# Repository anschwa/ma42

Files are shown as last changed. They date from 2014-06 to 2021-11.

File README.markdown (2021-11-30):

The MA42 Keyboard
=================

A programmable 42% mechanical keyboard for Dvorak.

Created by Michael Gobeli and Adam Schwartz.

With the help of:

- [jdcarpe](https://geekhack.org/index.php?action=profile;u=17386)
- [thechemist](https://geekhack.org/index.php?action=profile;u=27275)
- [geekhack.org](https://geekhack.org/index.php)

# Editor

[TMK Keymap Editor for MA42](http://anschwa.com/tmk_keyboard/editor/ma42/index.html).

Based on the [TMK Keymap Editor for the HHKB](http://www.tmk-kbd.com/tmk_keyboard/editor/hhkb/index.html).

# Photos

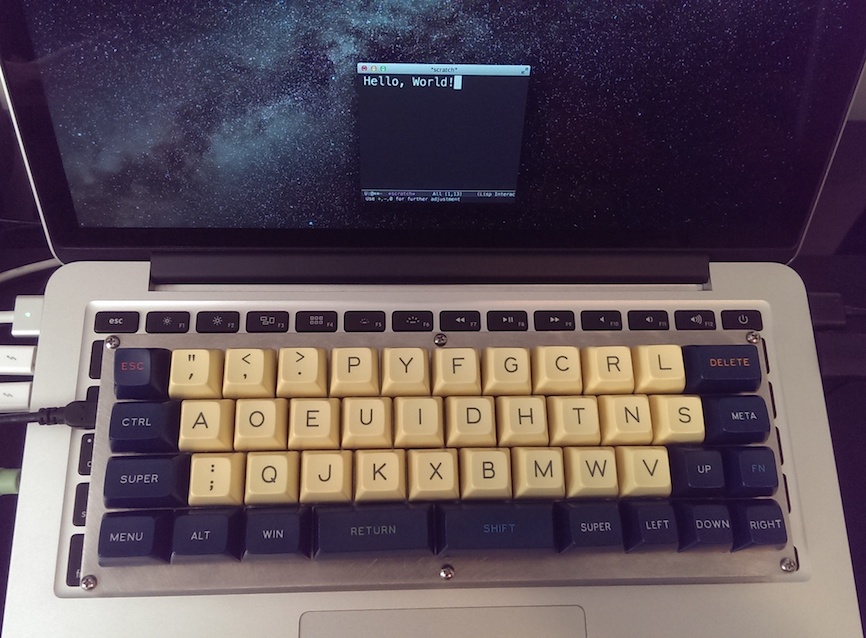
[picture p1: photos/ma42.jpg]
MA42 on top of rMBP


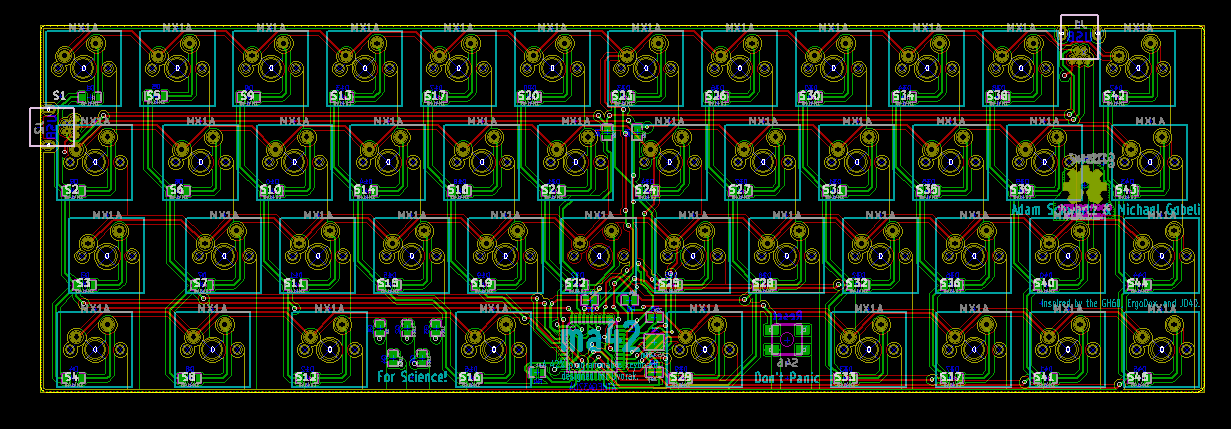
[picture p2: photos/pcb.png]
MA42 PCB revB


# License
The MA42 project is licensed under MIT unless otherwise noted.

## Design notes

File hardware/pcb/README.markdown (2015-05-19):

The MA42 PCB
============

The MA42 PCBs are licensed under [CC BY-SA 3.0](https://creativecommons.org/licenses/by-sa/3.0/us/).

However, this is due to a misunderstanding with the `GH60` licensing.

The `GH60` KiCad Source we accesed in July 2014 was distributed as "open source" without any explicit licence.

- [gh60 downloads 2014](https://web.archive.org/web/20140701221151/http://blog.komar.be/projects/gh60-programmable-keyboard/)

Currently, the `GH60` download page was updated with a `CC BY-SA 3.0` license sometime after October 17 2014 Many months after our projects completion.

- [gh60 downloads 2015+](http://blog.komar.be/projects/gh60-programmable-keyboard/)

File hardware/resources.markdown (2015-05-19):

## Articles
- [How to Design the Perfect PCB – Part 1](http://www.michaelhleonard.com/how-to-design-the-perfect-pcb-part1)
- [How to Design the Perfect PCB – Part 2](http://www.michaelhleonard.com/how-to-design-the-perfect-pcb-part2/)

## Videos
- [Solder ATmega32u4](http://vimeo.com/51312926)
- [Solder Crystal Oscillator](http://vimeo.com/51713766)

## GH60
- [How to make a keyboard - The Matrix](http://blog.komar.be/how-to-make-a-keyboard-the-matrix/)
- [GH60 GitHub](https://github.com/komar007/ghkb)

## ErgoDox
- [Ergodox GitHub](https://github.com/bishboria/ErgoDox)

## PCB Manufacturer
- [Advanced Circuits](http://www.4pcb.com/)
- [OSH Park](http://oshpark.com/)
- [ExpressPCB](http://www.expresspcb.com/)

## PCB Desgin Software
- [KiCad](http://www.kicad-pcb.org/display/KICAD/KiCad+EDA+Software+Suite)
- ~~[ExpressPCB](http://www.expresspcb.com/ExpressPCBHtm/Free_cad_software.htm)~~

## Schematics
- [Teensy](https://www.pjrc.com/teensy/schematic.html)

## Layout
- [Keyboard Layout Editor](http://www.keyboard-layout-editor.com/)

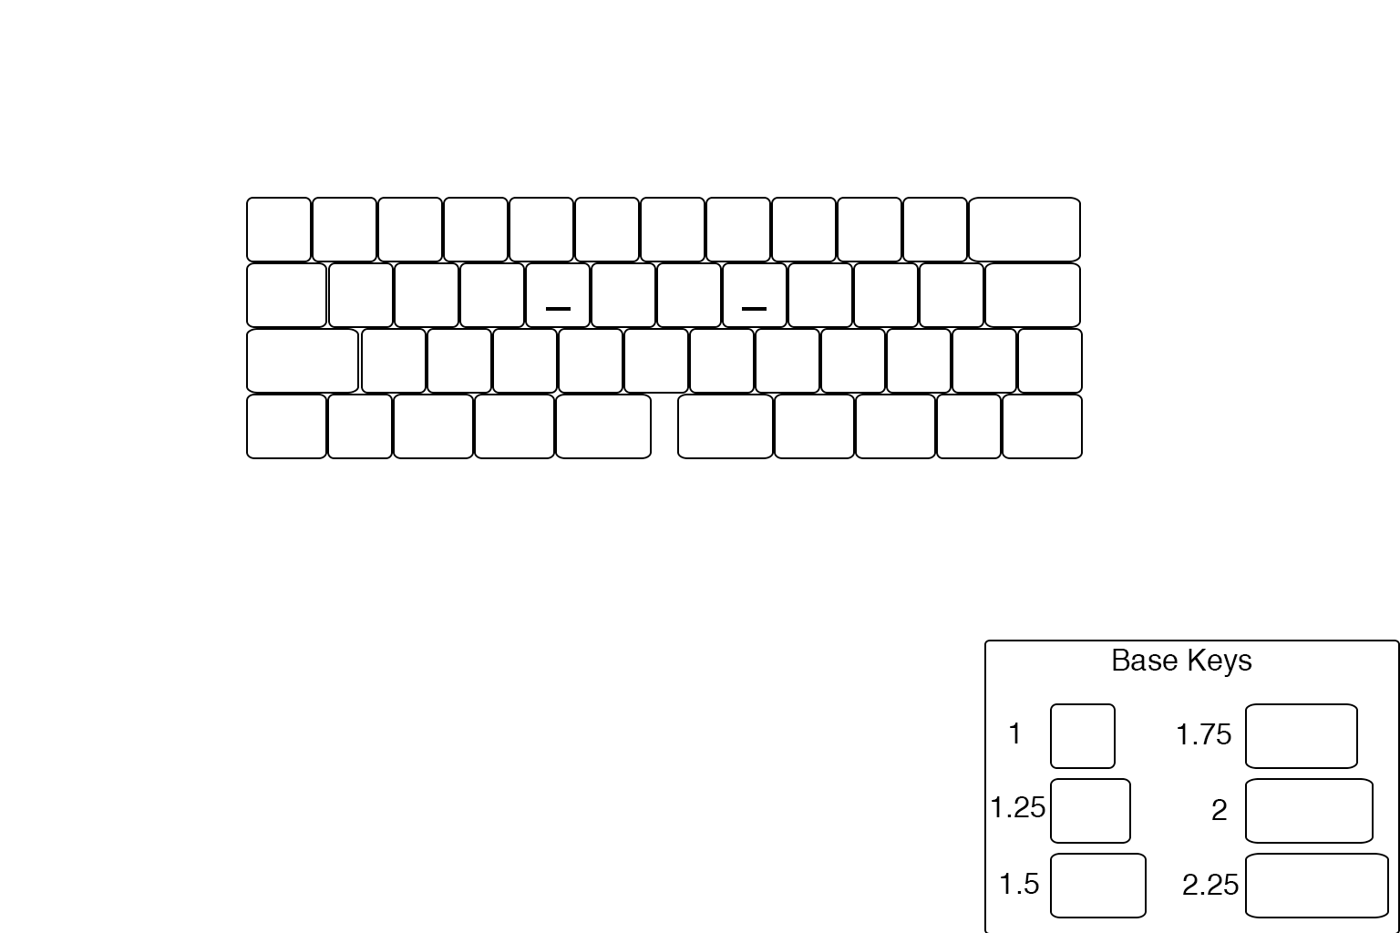
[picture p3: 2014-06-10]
hardware/layout/layout_b.png

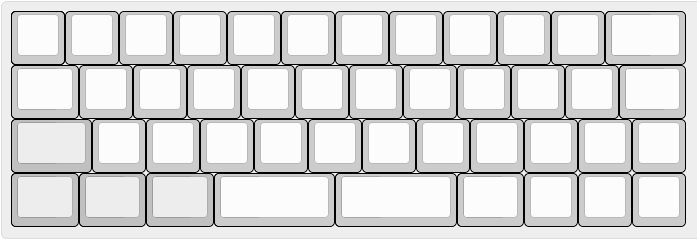
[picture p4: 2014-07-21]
hardware/layout/layout_d.png

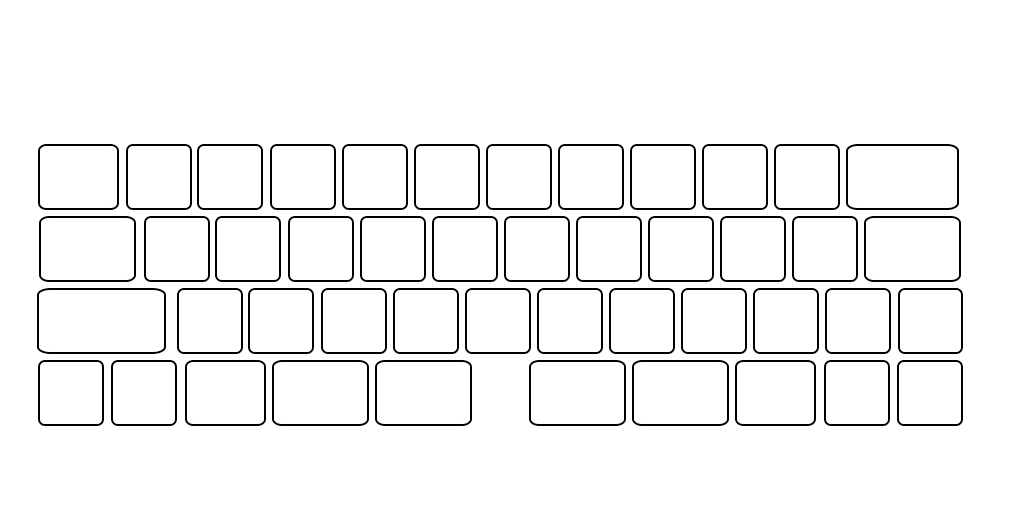
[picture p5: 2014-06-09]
hardware/layout/layout_a.png

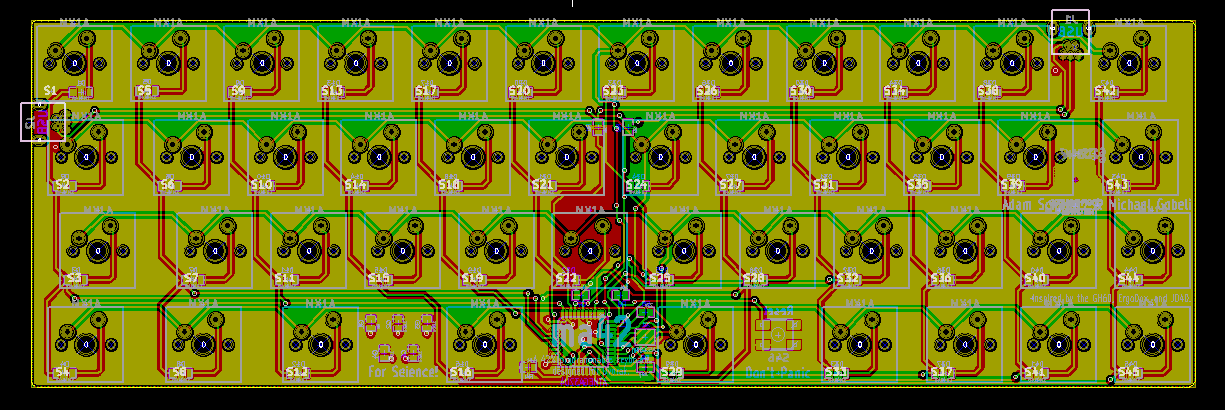
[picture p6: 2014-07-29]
hardware/pcb/revB/ma42_PCB_revB/resources/pcb1.PNG

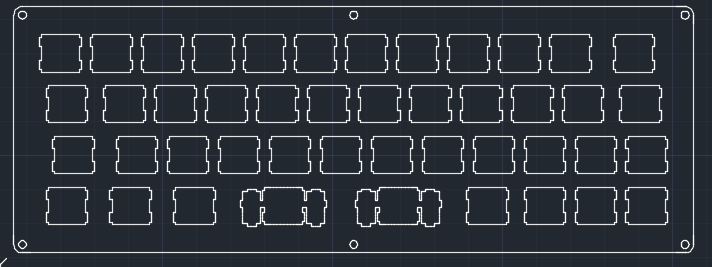
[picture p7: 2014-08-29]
hardware/case/revB/plate/Capture.PNG

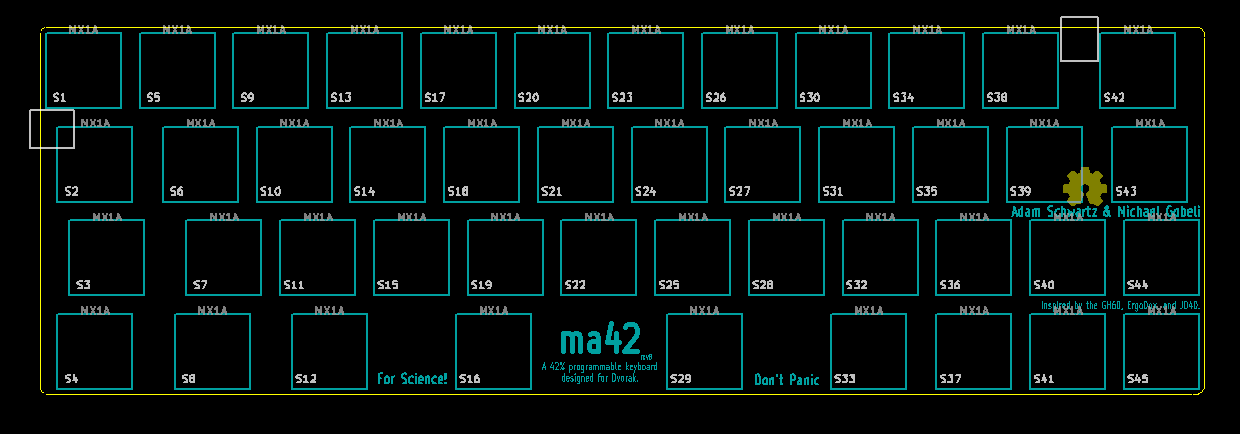
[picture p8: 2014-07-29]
hardware/pcb/revB/ma42_PCB_revB/resources/pcb3.PNG

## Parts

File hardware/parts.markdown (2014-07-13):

# Components Parts List

## Microcontroller
- [Leonardo Pro Micro](http://www.ebay.com/itm/Leonardo-Pro-Micro-ATmega32U4-Arduino-IDE-1-0-3-Bootloader-replace-Pro-Mini-/310634777706)
- [Teensy 2.0](http://www.adafruit.com/products/199)
- [ATMEGA32U4-AU](http://www.digikey.com/product-detail/en/ATMEGA32U4-AU/ATMEGA32U4-AU-ND/1914602) [available here](http://www.ebay.com/itm/1PCS-IC-ATMEL-TQFP-44-ATMEGA32U4-AU-MEGA32U4-AU-ATMEGA32U4-MEGA32U4-/360868648247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)

## Diodes

### Switch Diodes
- Surface Mount: [1N4148W-7-F](http://www.digikey.com/product-detail/en/1N4148W-7-F/1N4148W-FDICT-ND/815280)
- Through-Hole: [1N4148](http://www.digikey.com/product-detail/en/1N4148/1N4148FS-ND/458603)

## Capacitors
- [CC0805KKX7R8BB105](http://www.digikey.com/product-detail/en/08051A220KAT2A/478-3736-1-ND/1116434)
- [CC0805KKX7R8BB105](http://www.digikey.com/product-detail/en/CC0805KKX7R8BB105/311-1456-1-ND/2833762)
- [CC0805KRX7R9BB104](http://www.digikey.com/product-detail/en/CC0805KRX7R9BB104/311-1140-1-ND/303050) [available here](http://www.mouser.com/ProductDetail/Yageo/CC0805KRX7R9BB104/?qs=vTakOoo5QyLx0lXWgVtRhQ==)

## Resistors
- [RC0805FR-0710KL](http://www.digikey.com/product-detail/en/RC0805FR-0710KL/311-10.0KCRCT-ND/730482) [available here](http://www.mouser.com/ProductDetail/Yageo/RC0805FR-0710KL/?qs=7bY8808IzHq6vrU3BeiiYw==)
- [RC0805JR-0722RL](http://www.digikey.com/product-detail/en/RC0805JR-0722RL/311-22ARCT-ND/731232)

## Mini USB
- [0548190519 (ErgoDox)](http://www.digikey.com/product-detail/en/0548190519/WM17115-ND/773802)
- [0675031020 (GH60)](http://www.digikey.com/product-detail/en/0675031020/WM5461CT-ND/1624427)

## Crystal Oscillator
- [NX3225GA-16MHZ- STD-CRG-1](http://www.digikey.com/product-detail/en/NX3225GA-16MHZ-%20STD-CRG-1/644-1174-1-ND/3125563)
- [NX3225GA-26MHZ-TI](http://www.digikey.com/product-detail/en/NX3225GA-26MHZ-TI/644-1160-1-ND/2349038)

## Reset Switch
[KSEM31G LFS](http://www.digikey.com/product-detail/en/KSEM31G%20LFS/CKN10424CT-ND/3487193)

## Switch Stabilizers
- [spring](http://www.wasdkeyboards.com/index.php/products/keyboard-parts/cherry-mx-stabilizer-spring-for-2x-keycaps.html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)
- [insert](http://www.wasdkeyboards.com/index.php/products/keyboard-parts/cherry-mx-keycap-stabilizer-insert-2pcs.html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)
- [clip](http://www.wasdkeyboards.com/index.php/products/keyboard-parts/cherry-mx-plate-mounted-stabilizer-clips-2pcs.html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)

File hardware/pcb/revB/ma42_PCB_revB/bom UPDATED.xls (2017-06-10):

物料清单BOM
Manufacturer生产商 | Manufacturer Part Number生产商编号 | Designator位置 | Qty数量 | Description描述(值，耐压，精度μF) | Case 封装 | SMD ,BGA,LLC(QFN),OR TH | points点数 | points | Top/Bottom顶层/底层 | 厂家 | 厂家物料号 | 描述 | 采购备注 | MOQ10 | Customer reply
AVX | 08051A220KAT2A | C1, C2, C6, C8 | 2 | 22pF,100V,10%,C0G,0805 | 0805 | SMD | 2 | 4 | Bottom | AVX | 08051A220KAT2A
YAGEO | CC0805KKX7R8BB105 | C3 | 2 | 1uF,25V,10%,X7R,0805 | 0805 | SMD | 2 | 4 | Bottom | YAGEO | CC0805KKX7R8BB105
YAGEO | CC0805KRX7R9BB104 | C4, C5, C7 | 4 | 100nF,50V,10%,X7R,0805 | 0805 | SMD | 2 | 8 | Bottom | YAGEO | CC0805KRX7R9BB104
Yageo | RC0805JR-0722RL | R1, R2 | 2 | 22R,5%,1/8W,0805 | 0805 | SMD | 2 | 4 | Bottom | Yageo | RC0805JR-0722RL
Yageo | RC0805FR-0710KL | R3, R5 | 2 | 10K,1%,1/8W,0805 | 0805 | SMD | 2 | 4 | Bottom | Yageo | RC0805FR-0710KL
Crownpo | CD4148WS | D01, D02, D03, D04, D05, D06, D07, D08, D09, D10, D11, D12, D13, D14, D15, D16, D17, D18, D19, D21, D22, D23, D24, D26, D27, D28, D29, D30, D31, D32, D33, D34, D36, D37, D38, D39, D41, D42, D43, D44, D46, D47, D48, D49, D50, D51, D52, D53, D54, D55, D56, D57, D58, D59, D60, D61, D62, D63, D64, D65, D66, D67, D68, D69, D70 | 65 | 100V,150mA,0805 | 0805 | SMD | 2 | 130 | Bottom | Crownpo | CD4148WS
NDK | NX3225GA-16MHZ- STD-CRG-2 | X1 | 1 | 16MHz,8pF,4-SMD(3.2mmL*2.5mmW*0.9mmH) | 4-SMD | SMD | 4 | 4 | Bottom | NDK | NX3225GA-16MHZ- STD-CRG-2
Atmel | ATMEGA32U4-AUR | IC1 | 1 | ATMEGA32U4-AUR,44-TQFP | 44-TQFP | SMD | 44 | 44 | Bottom | Atmel | ATMEGA32U4-AU
C&K Components | Y17K20502FP LFS | S0 | 1 | 32VDC,0.05A,6.2mmL*6.2mmW*3.1mmH | 6.2mmL*6.2mmW*3.1mmH | SMD | 4 | 4 | Bottom | C&K Components | KSEM31G LFS |  | We need to buy MOQ 50pcs.KSEM31G LFS and Y17K20502FP LFS are same component. We could send unused components with your boards. | 50 | could you keep the rest of the switches for later orders?
Molex | 0675031020 | J1 | 1 | USB 2.0 OTG,mini B,right angle | see link | SMD | 9 | 9 | Bottom | Molex | 675031020
 |  | All components assembled on bottom side.

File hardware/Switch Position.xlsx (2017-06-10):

Origin R1,C1 | C1 | C2 | C3 | C4 | C5 | C6 | C7 | C8 | C9 | C10 | C11 | C12 | Y Values
R1 | 0 | 0.75 | 1.5 | 2.25 | 3 | 3.75 | 4.5 | 5.25 | 6 | 6.75 | 7.5 | 8.4375 | 0
R2 | 0.09375 | 0.9375 | 1.6875 | 2.4375 | 3.1875 | 3.9375 | 4.6875 | 5.4375 | 6.1875 | 6.9375 | 7.6875 | 8.53125 | 0.75
R3 | 0.1875 | 1.125 | 1.875 | 2.625 | 3.375 | 4.125 | 4.875 | 5.625 | 6.375 | 7.125 | 7.875 | 8.625 | 1.5
R4 | 0.09375 | 1.03125 | 1.96875 |  | 3.28125 |  | 4.96875 |  | 6.28125 | 7.125 | 7.875 | 8.625 | 2.25

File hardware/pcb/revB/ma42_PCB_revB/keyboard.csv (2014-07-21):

Id | Designator | Package | Quantity | Designation | Supplier and ref
1 | IC1 | TQFP44 | 1 | ATMEGA32U4
2 | D27,D15,D16,D17,D25,D1,D19,D13,D26,D29,D33,D30,D31,D18,D35,D14,D34,D24,D23,D22,D21,D12,D8,D11,D10,D5,D9,D2,D6,D7,D36,D37,D39,D40,D38,D44,D41,D43,D42,D20,D28,D32,D4,D3 | SM0805D | 44 | 1N4148
3 | C5,C3,C6,C2 | SM0805 | 4 | 100n
4 | C7,C1 | SM0805 | 2 | 1u
5 | R1,R2 | SM0805 | 2 | 22
6 | C8,C4 | SM0805 | 2 | 22p
7 | R4,R3 | R3 | 2 | 10k
8 | S5,S17,S25,S4,S43,S38,S35,S31,S27,S23,S19,S15,S11,S7,S3,S26,S40,S37,S30,S22,S18,S14,S10,S6,S2,S41,S34,S33,S29,S21,S13,S9,S45,S42,S39,S36,S32,S28,S24,S20,S16,S12,S8,S44 | MX1A-b | 44 | MX1A
9 | X1 | ASX3F | 1 | ASX3F
10 | S1 | DTSJW-66N | 1 | Reset
11 | J1,J2 | USBMINImod | 2 | USB
12 | G*** | OSHW | 1 | OSHW
13 | G*** | OSHWT | 1 | OSHWT

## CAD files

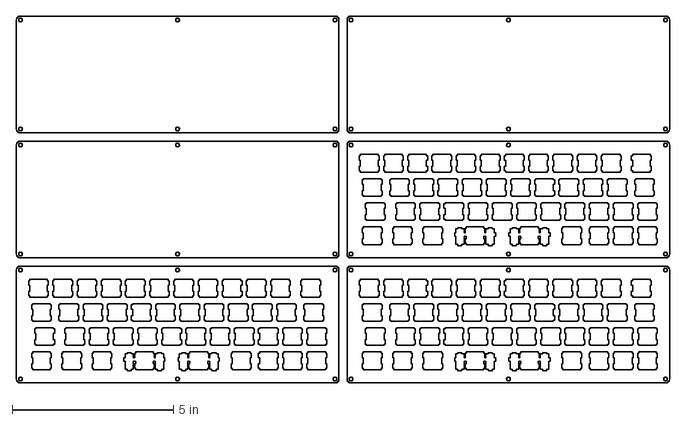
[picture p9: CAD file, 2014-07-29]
hardware/case/revB/plate/MA42 Standard.dxf
20.3 x 11.4 in

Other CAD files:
hardware/case/revB/plate/Mid Layer Design.dwg
hardware/case/revA/plate/MA42.dwg
hardware/case/revB/3D/Assembly1.iam
hardware/case/revB/3D/Base.ipt
hardware/case/revB/3D/Mid.ipt
hardware/case/revB/3D/OldVersions/Assembly1.0002.iam
hardware/case/revB/3D/OldVersions/Assembly1.0003.iam
hardware/case/revB/3D/OldVersions/Base.0002.ipt
hardware/case/revB/3D/OldVersions/Mid.0002.ipt
hardware/case/revB/3D/OldVersions/Spacer.0001.ipt
hardware/case/revB/3D/Spacer.ipt
hardware/case/revB/plate/MA42 Standard.dwg

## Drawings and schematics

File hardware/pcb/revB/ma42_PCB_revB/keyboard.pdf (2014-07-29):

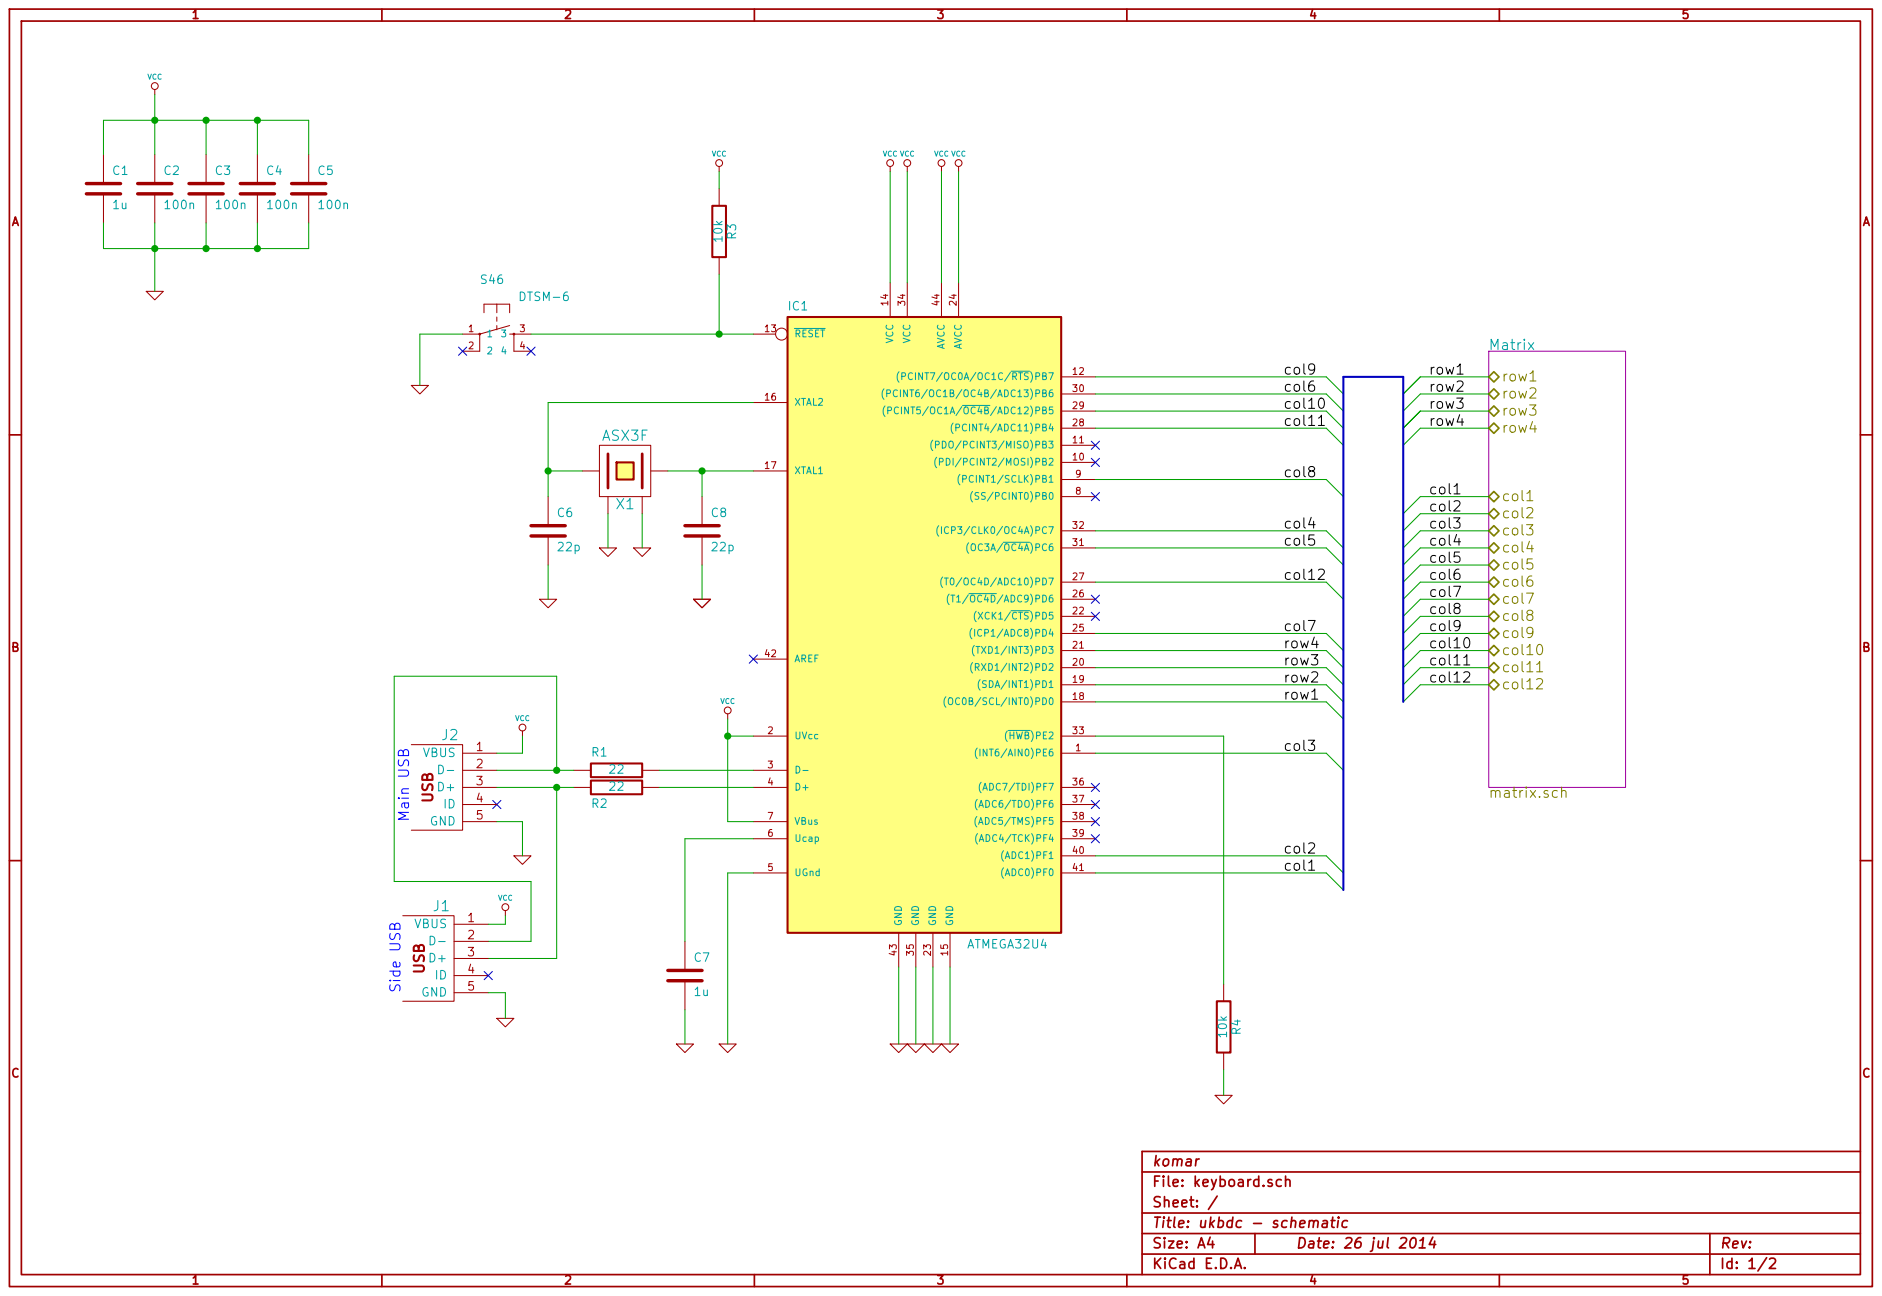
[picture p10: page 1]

Sheet: / komar
Id: 1/2 Title: ukbdc - schematic File: keyboard.sch

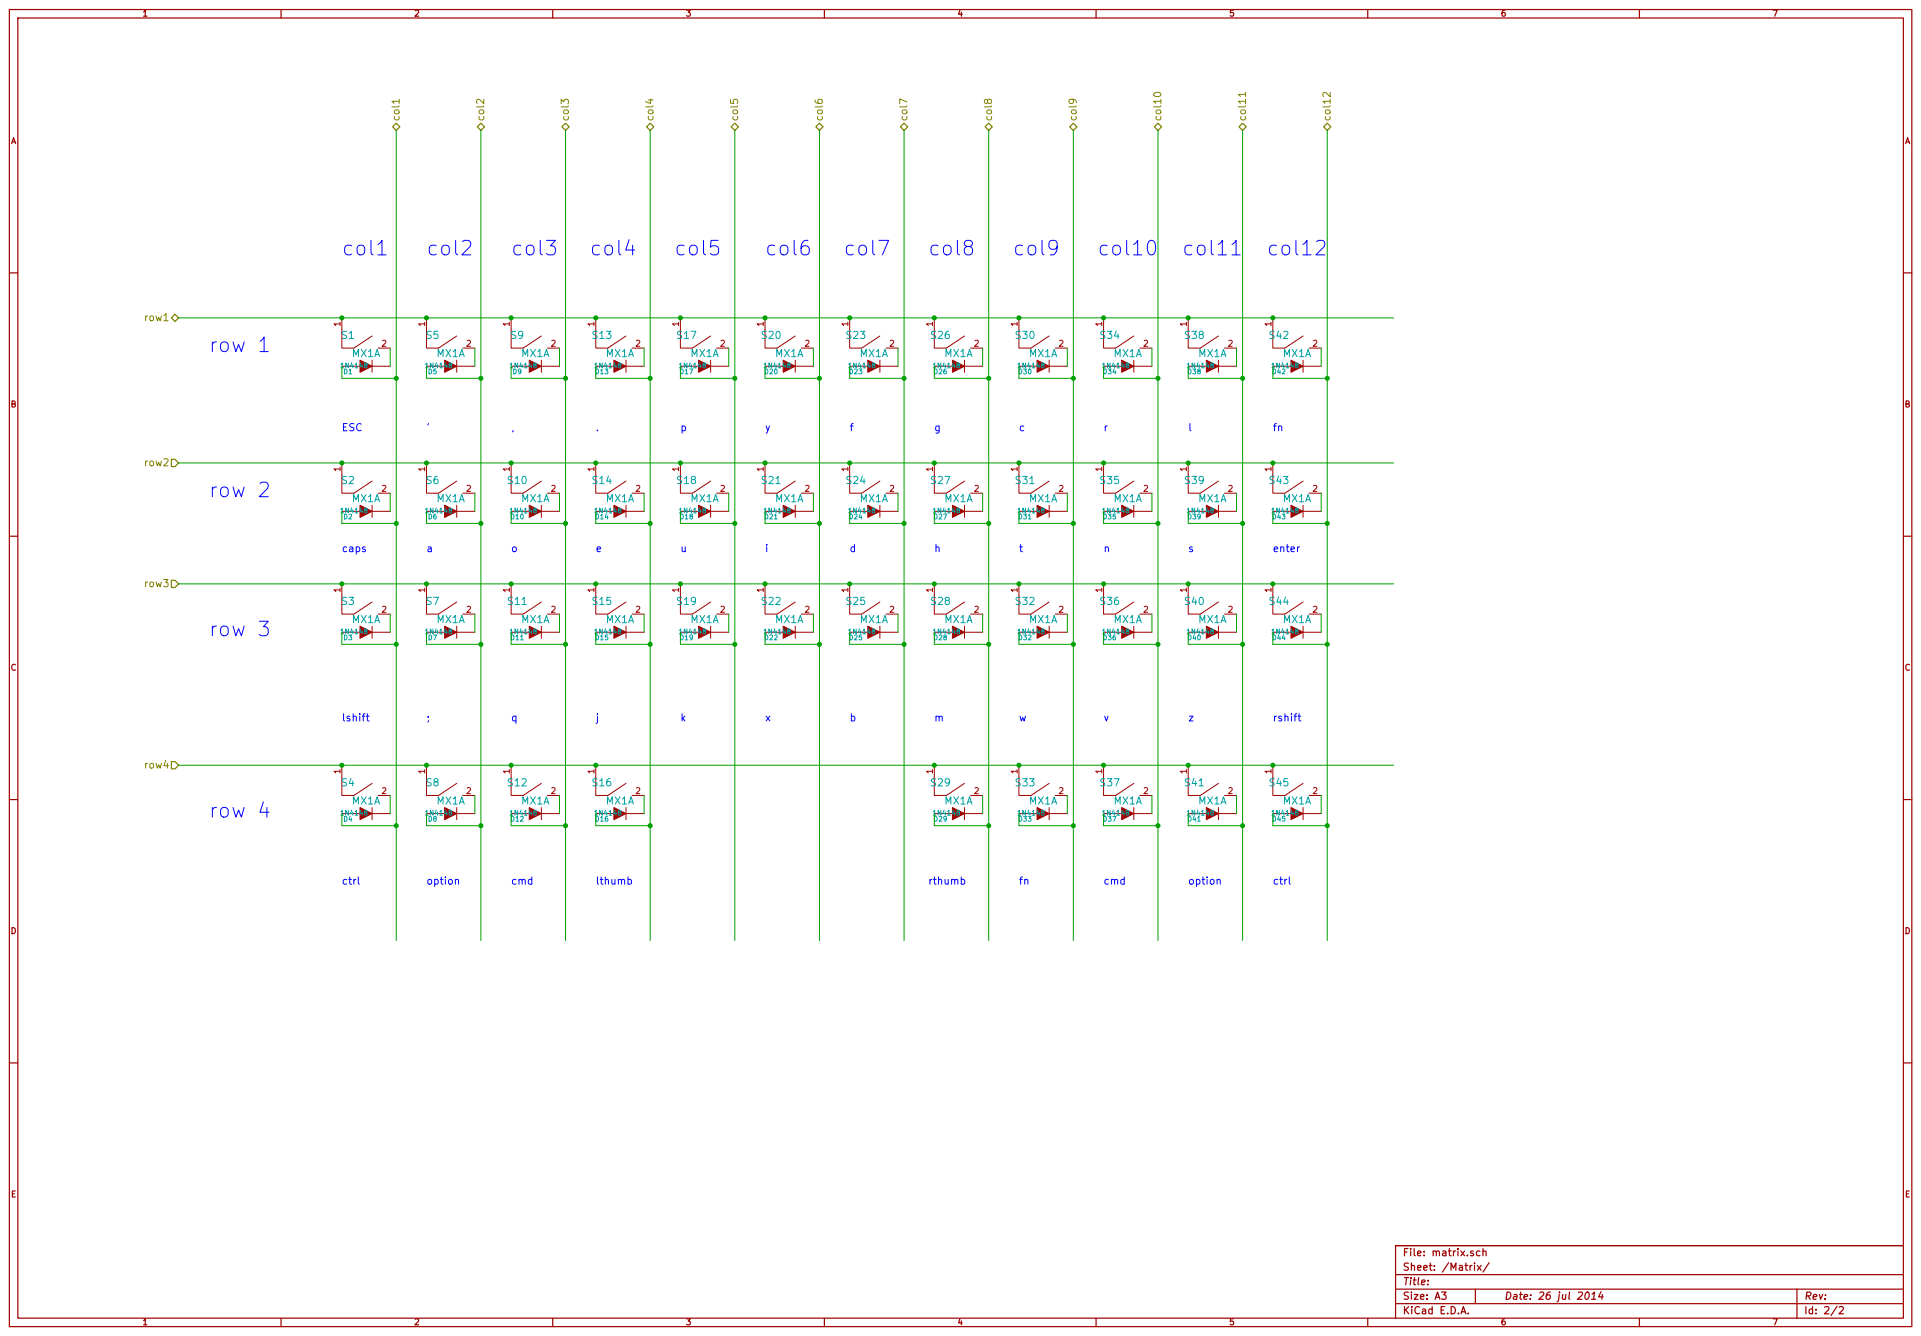
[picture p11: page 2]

Id: 2/2 Title: File: matrix.sch Sheet: /Matrix/

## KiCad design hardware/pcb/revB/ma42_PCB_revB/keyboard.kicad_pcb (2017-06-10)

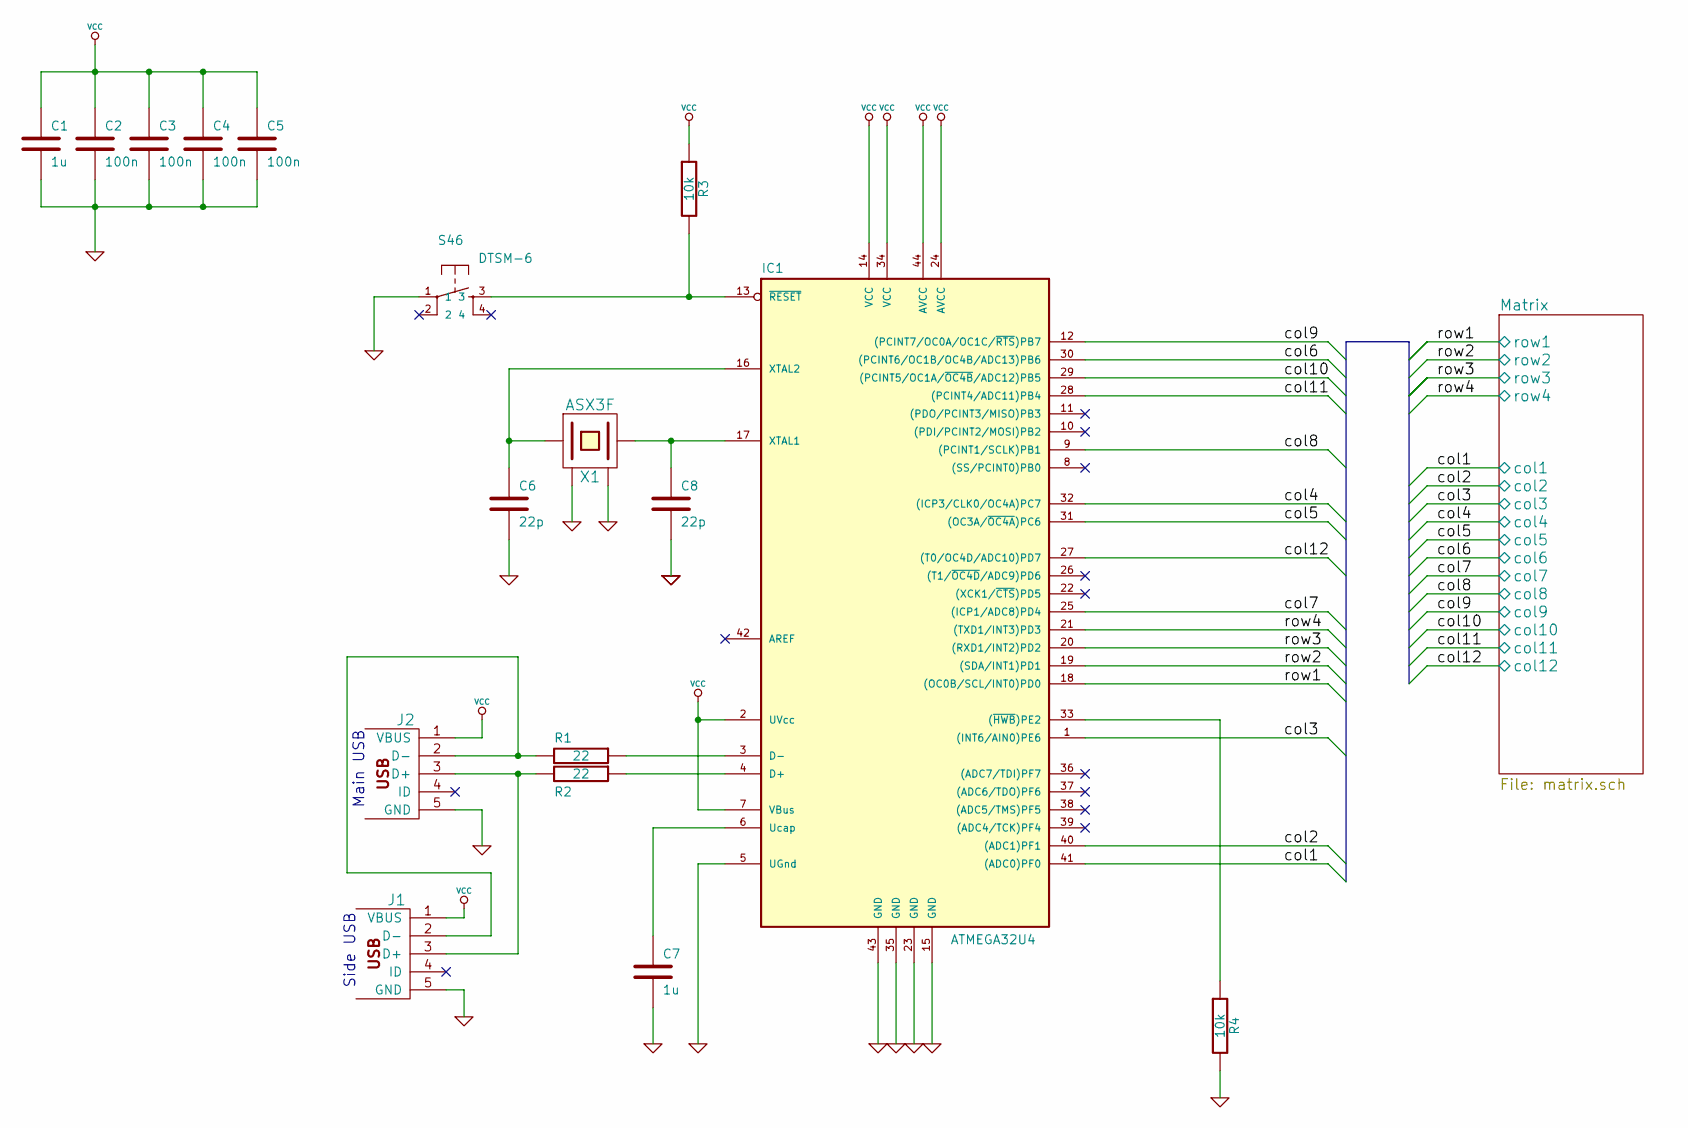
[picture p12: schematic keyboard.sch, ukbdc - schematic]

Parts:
C1, C7: 1u
C2, C3, C4, C5: 100n
C6, C8: 22p
IC1: ATMEGA32U4; TQFP44
J1: USBMINI_B05
J2: MINI
R1, R2: 22
R3, R4: 10k
S46: DTSM-6; switch-tact-DTSM-6
X1: ASX3F

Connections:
/Matrix/col1: IC1.41 ((ADC0)PF0); also elsewhere on the board
/Matrix/col2: IC1.40 ((ADC1)PF1); also elsewhere on the board
/Matrix/col3: IC1.1 ((INT6/AIN0)PE6); also elsewhere on the board
/Matrix/col4: IC1.32 ((ICP3/CLK0/OC4A)PC7); also elsewhere on the board
/Matrix/col5: IC1.31 ((OC3A/~OC4A~)PC6); also elsewhere on the board
/Matrix/col6: IC1.30 ((PCINT6/OC1B/OC4B/ADC13)PB6); also elsewhere on the board
/Matrix/col7: IC1.25 ((ICP1/ADC8)PD4); also elsewhere on the board
/Matrix/col8: IC1.9 ((PCINT1/SCLK)PB1); also elsewhere on the board
/Matrix/col9: IC1.12 ((PCINT7/OC0A/OC1C/~RTS~)PB7); also elsewhere on the board
/Matrix/col10: IC1.29 ((PCINT5/OC1A/~OC4B~/ADC12)PB5); also elsewhere on the board
/Matrix/col11: IC1.28 ((PCINT4/ADC11)PB4); also elsewhere on the board
/Matrix/col12: IC1.27 ((T0/OC4D/ADC10)PD7); also elsewhere on the board
/Matrix/row1: IC1.18 ((OC0B/SCL/INT0)PD0); also elsewhere on the board
/Matrix/row2: IC1.19 ((SDA/INT1)PD1); also elsewhere on the board
/Matrix/row3: IC1.20 ((RXD1/INT2)PD2); also elsewhere on the board
/Matrix/row4: IC1.21 ((TXD1/INT3)PD3); also elsewhere on the board
GND: C1.2, C2.2, C3.2, C4.2, C5.2, C6.2, C7.2, C8.2, IC1.5 (UGnd), IC1.15 (GND), IC1.23 (GND), IC1.35 (GND), IC1.43 (GND), J1.5 (GND), J2.5 (GND), R4.2, S46.1, X1.2 (GND), X1.4 (GND)
unnamed: IC1.33 ((~HWB~)PE2), R4.1
unnamed: J1.3 (D+), J2.3 (D+), R2.2
unnamed: IC1.13 (~RESET~), R3.2, S46.3
unnamed: J1.2 (D-), J2.2 (D-), R1.2
unnamed: C7.1, IC1.6 (Ucap)
unnamed: IC1.4 (D+), R2.1
unnamed: IC1.3 (D-), R1.1
unnamed: C6.1, IC1.16 (XTAL2), X1.1
unnamed: C8.1, IC1.17 (XTAL1), X1.3 (2)
VCC: C1.1, C2.1, C3.1, C4.1, C5.1, IC1.2 (UVcc), IC1.7 (VBus), IC1.14 (VCC), IC1.24 (AVCC), IC1.34 (VCC), IC1.44 (AVCC), J1.1 (VBUS), J2.1 (VBUS), R3.1

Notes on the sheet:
Side USB
Main USB

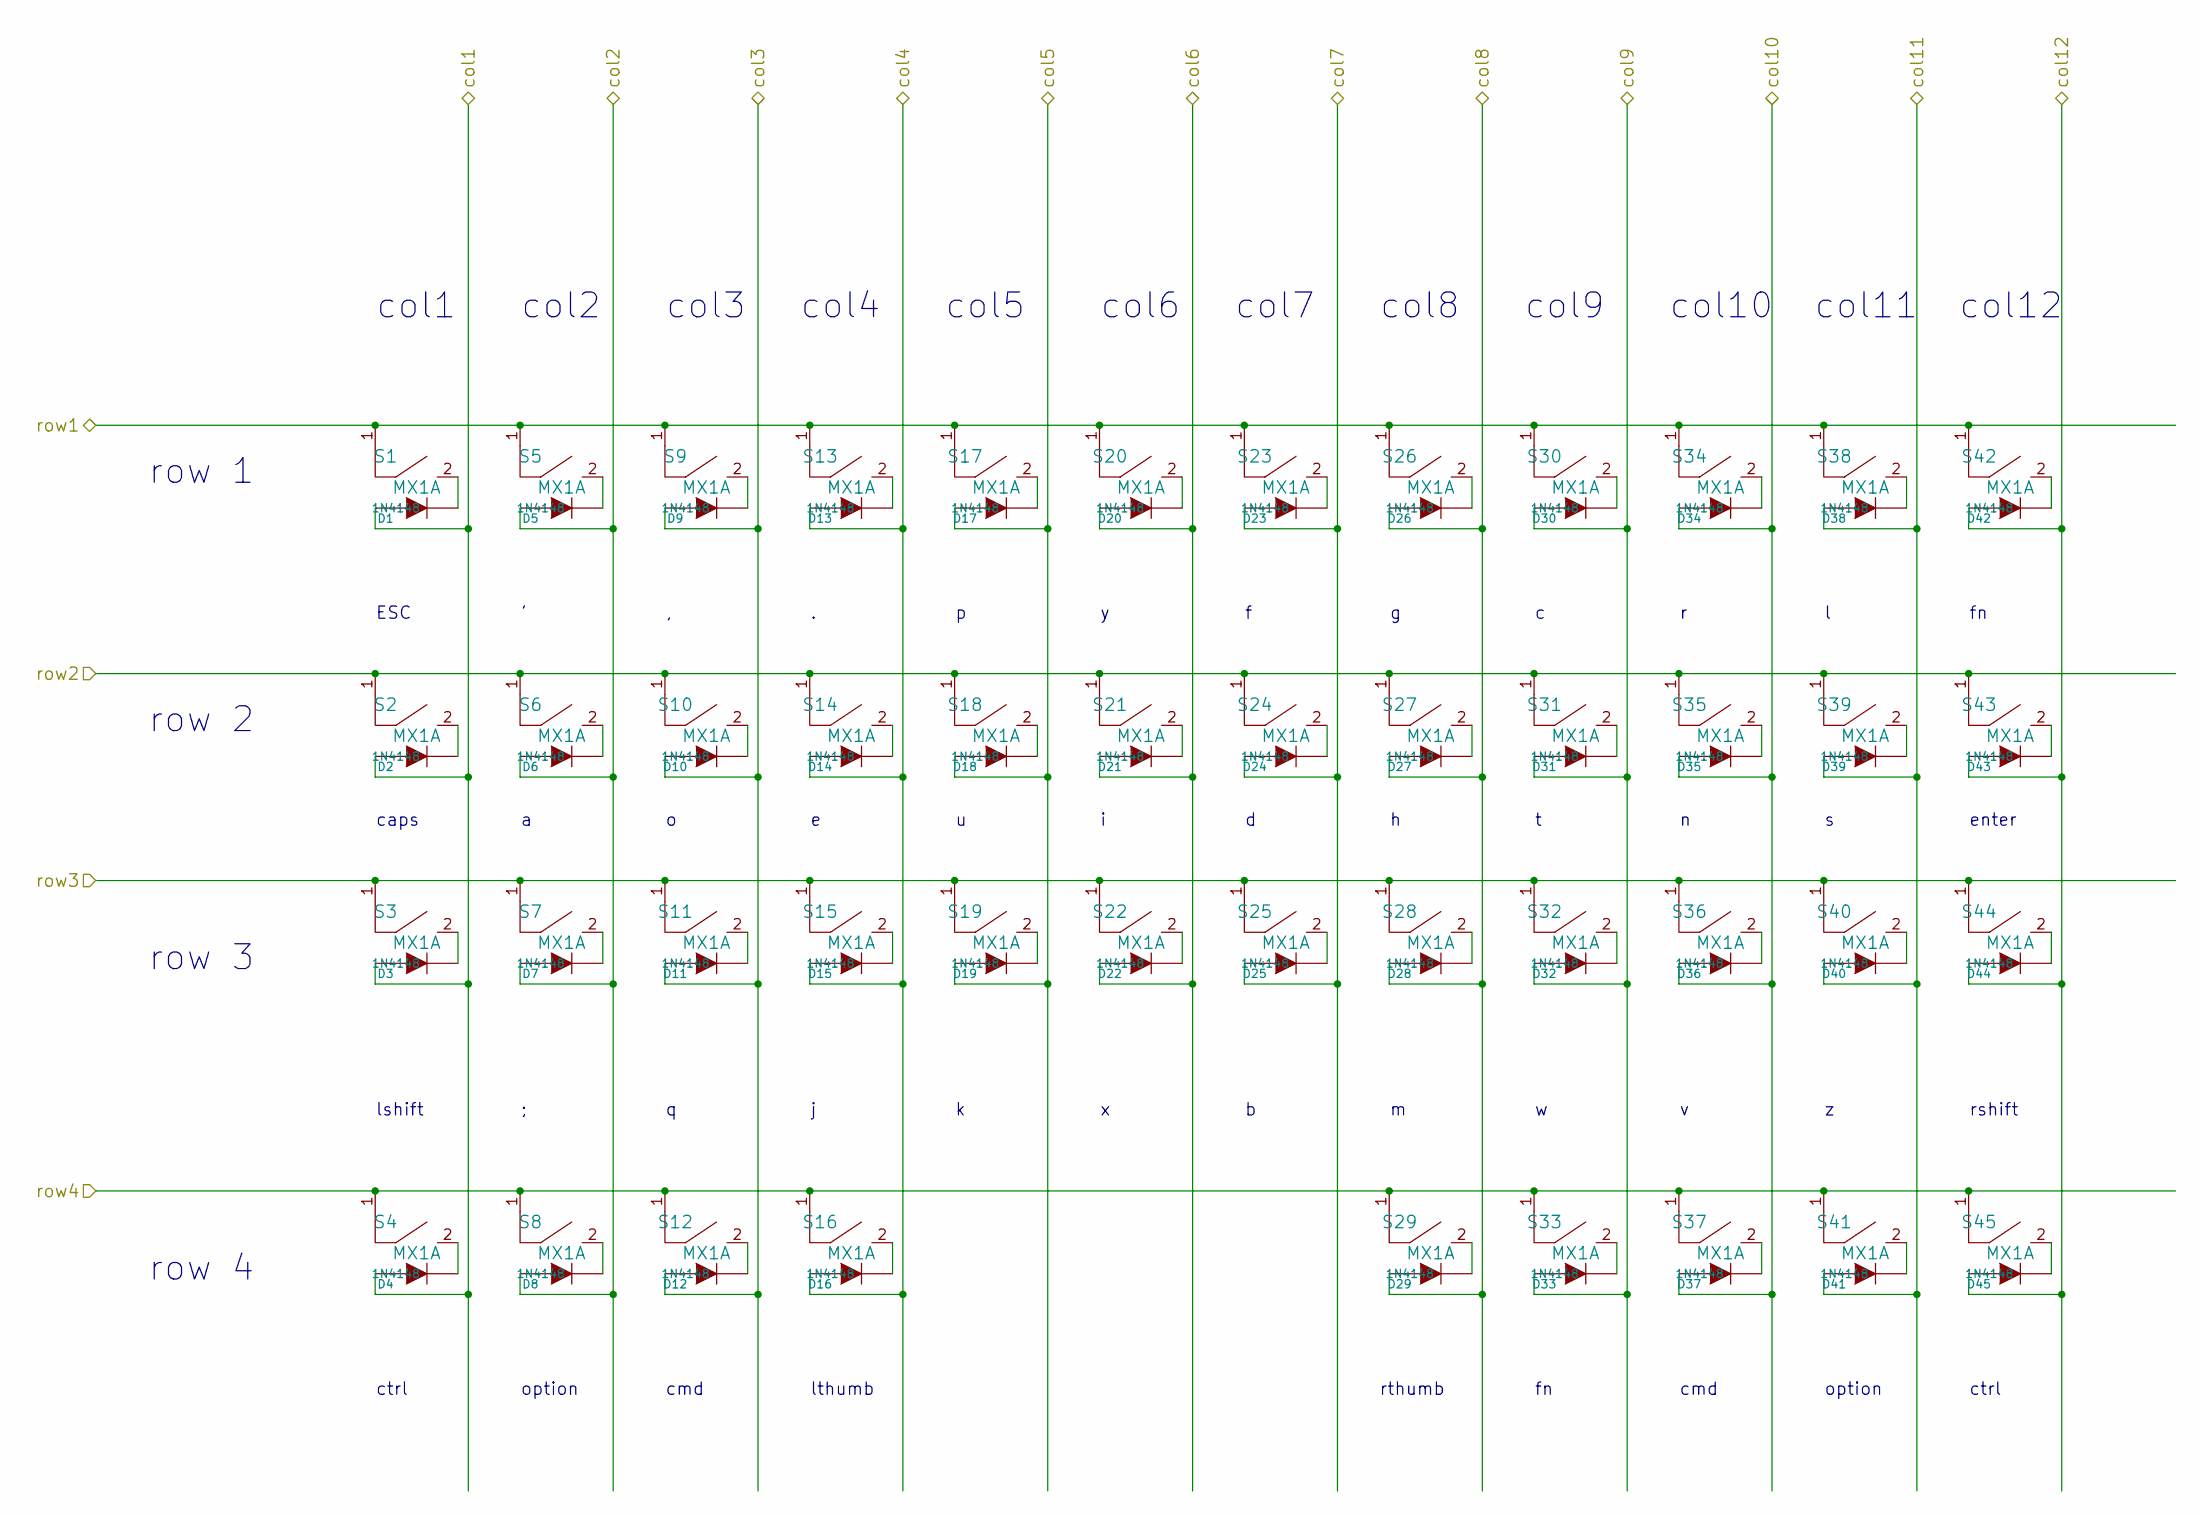
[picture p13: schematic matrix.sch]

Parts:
D1, D2, D3, D4, D5, D6, D7, D8, D9, D10, D11, D12, D13, D14, D15, D16, D17, D18, D19, D20, D21, D22, D23, D24, D25, D26, D27, D28, D29, D30, D31, D32, D33, D34, D35, D36, D37, D38, D39, D40, D41, D42, D43, D44, D45: 1N4148
S1, S2, S3, S4, S5, S6, S7, S8, S9, S10, S11, S12, S13, S14, S15, S16, S17, S18, S19, S20, S21, S22, S23, S24, S25, S26, S27, S28, S29, S30, S31, S32, S33, S34, S35, S36, S37, S38, S39, S40, S41, S42, S43, S44, S45: MX1A

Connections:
/Matrix/col1: D1.1 (A), D2.1 (A), D3.1 (A), D4.1 (A); also elsewhere on the board
/Matrix/col2: D5.1 (A), D6.1 (A), D7.1 (A), D8.1 (A); also elsewhere on the board
/Matrix/col3: D9.1 (A), D10.1 (A), D11.1 (A), D12.1 (A); also elsewhere on the board
/Matrix/col4: D13.1 (A), D14.1 (A), D15.1 (A), D16.1 (A); also elsewhere on the board
/Matrix/col5: D17.1 (A), D18.1 (A), D19.1 (A); also elsewhere on the board
/Matrix/col6: D20.1 (A), D21.1 (A), D22.1 (A); also elsewhere on the board
/Matrix/col7: D23.1 (A), D24.1 (A), D25.1 (A); also elsewhere on the board
/Matrix/col8: D26.1 (A), D27.1 (A), D28.1 (A), D29.1 (A); also elsewhere on the board
/Matrix/col9: D30.1 (A), D31.1 (A), D32.1 (A), D33.1 (A); also elsewhere on the board
/Matrix/col10: D34.1 (A), D35.1 (A), D36.1 (A), D37.1 (A); also elsewhere on the board
/Matrix/col11: D38.1 (A), D39.1 (A), D40.1 (A), D41.1 (A); also elsewhere on the board
/Matrix/col12: D42.1 (A), D43.1 (A), D44.1 (A), D45.1 (A); also elsewhere on the board
/Matrix/row1: S1.1, S5.1, S9.1, S13.1, S17.1, S20.1, S23.1, S26.1, S30.1, S34.1, S38.1, S42.1; also elsewhere on the board
/Matrix/row2: S2.1, S6.1, S10.1, S14.1, S18.1, S21.1, S24.1, S27.1, S31.1, S35.1, S39.1, S43.1; also elsewhere on the board
/Matrix/row3: S3.1, S7.1, S11.1, S15.1, S19.1, S22.1, S25.1, S28.1, S32.1, S36.1, S40.1, S44.1; also elsewhere on the board
/Matrix/row4: S4.1, S8.1, S12.1, S16.1, S29.1, S33.1, S37.1, S41.1, S45.1; also elsewhere on the board
unnamed: D19.2 (K), S19.2
unnamed: D1.2 (K), S1.2
unnamed: D26.2 (K), S26.2
unnamed: D25.2 (K), S25.2
unnamed: D24.2 (K), S24.2
unnamed: D23.2 (K), S23.2
unnamed: D17.2 (K), S17.2
unnamed: D38.2 (K), S38.2
unnamed: D35.2 (K), S35.2
unnamed: D34.2 (K), S34.2
unnamed: D31.2 (K), S31.2
unnamed: D32.2 (K), S32.2
unnamed: D18.2 (K), S18.2
unnamed: D28.2 (K), S28.2
unnamed: D27.2 (K), S27.2
unnamed: D30.2 (K), S30.2
unnamed: D20.2 (K), S20.2
unnamed: D12.2 (K), S12.2
unnamed: D8.2 (K), S8.2
unnamed: D11.2 (K), S11.2
unnamed: D21.2 (K), S21.2
unnamed: D10.2 (K), S10.2
unnamed: D7.2 (K), S7.2
unnamed: D6.2 (K), S6.2
unnamed: D2.2 (K), S2.2
unnamed: D16.2 (K), S16.2
unnamed: D15.2 (K), S15.2
unnamed: D14.2 (K), S14.2
unnamed: D13.2 (K), S13.2
unnamed: D37.2 (K), S37.2
unnamed: D22.2 (K), S22.2
unnamed: D4.2 (K), S4.2
unnamed: D3.2 (K), S3.2
unnamed: D29.2 (K), S29.2
unnamed: D45.2 (K), S45.2
unnamed: D41.2 (K), S41.2
unnamed: D33.2 (K), S33.2
unnamed: D42.2 (K), S42.2
unnamed: D43.2 (K), S43.2
unnamed: D40.2 (K), S40.2
unnamed: D44.2 (K), S44.2
unnamed: D36.2 (K), S36.2
unnamed: D39.2 (K), S39.2
unnamed: D9.2 (K), S9.2
unnamed: D5.2 (K), S5.2

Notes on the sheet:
row 1
row 2
row 3
row 4
col1
col2
col3
col4
col5
col6
col7
col9
col10
col11
col12
col8
ESC
caps
enter
rshift
ctrl
option
cmd
lthumb
lshift
rthumb

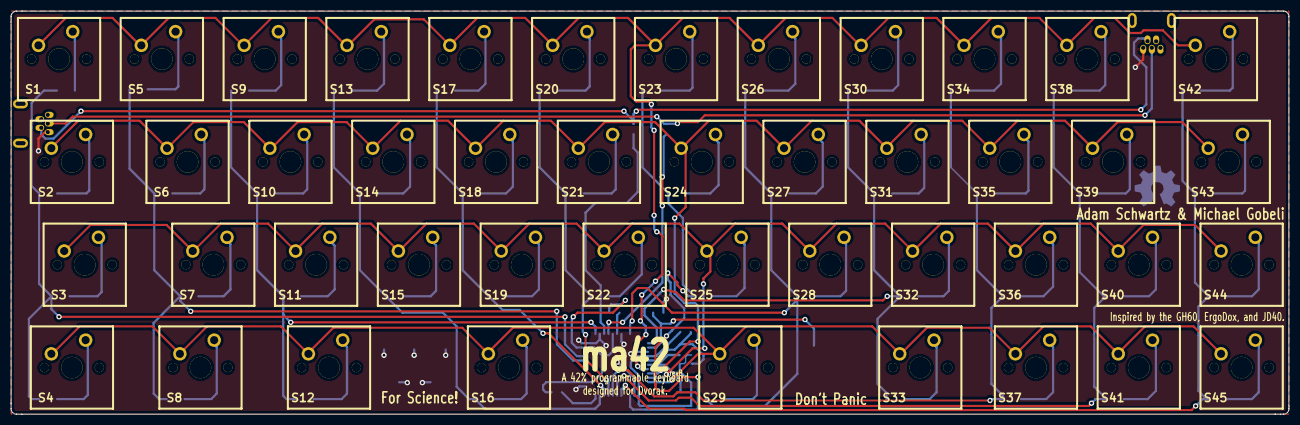
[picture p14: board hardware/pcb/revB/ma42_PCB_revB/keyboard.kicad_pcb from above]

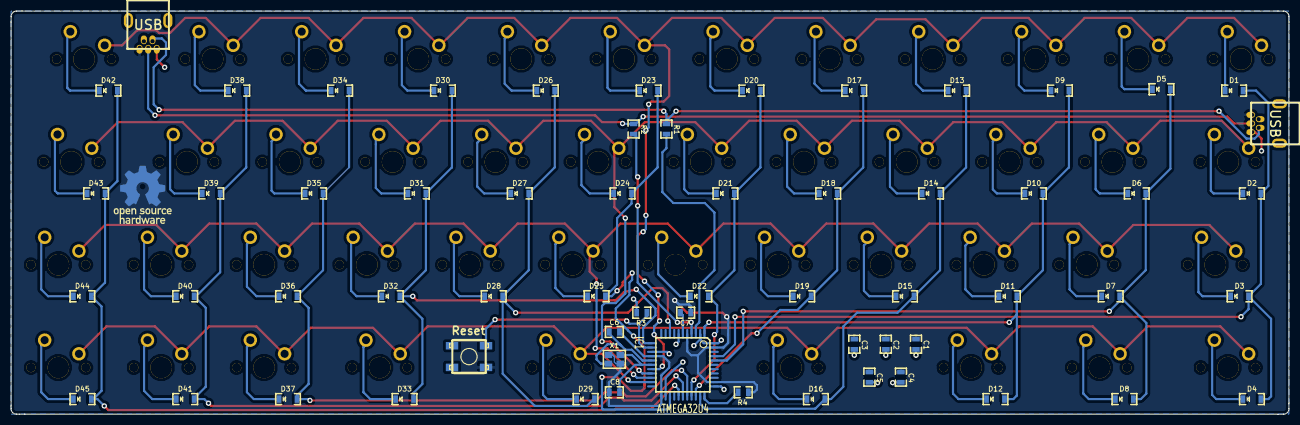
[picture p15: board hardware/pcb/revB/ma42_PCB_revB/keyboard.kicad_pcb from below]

Board: 2 copper layers, 236.7 x 74.7 mm, 107 parts (62 on the bottom side), 72 nets.

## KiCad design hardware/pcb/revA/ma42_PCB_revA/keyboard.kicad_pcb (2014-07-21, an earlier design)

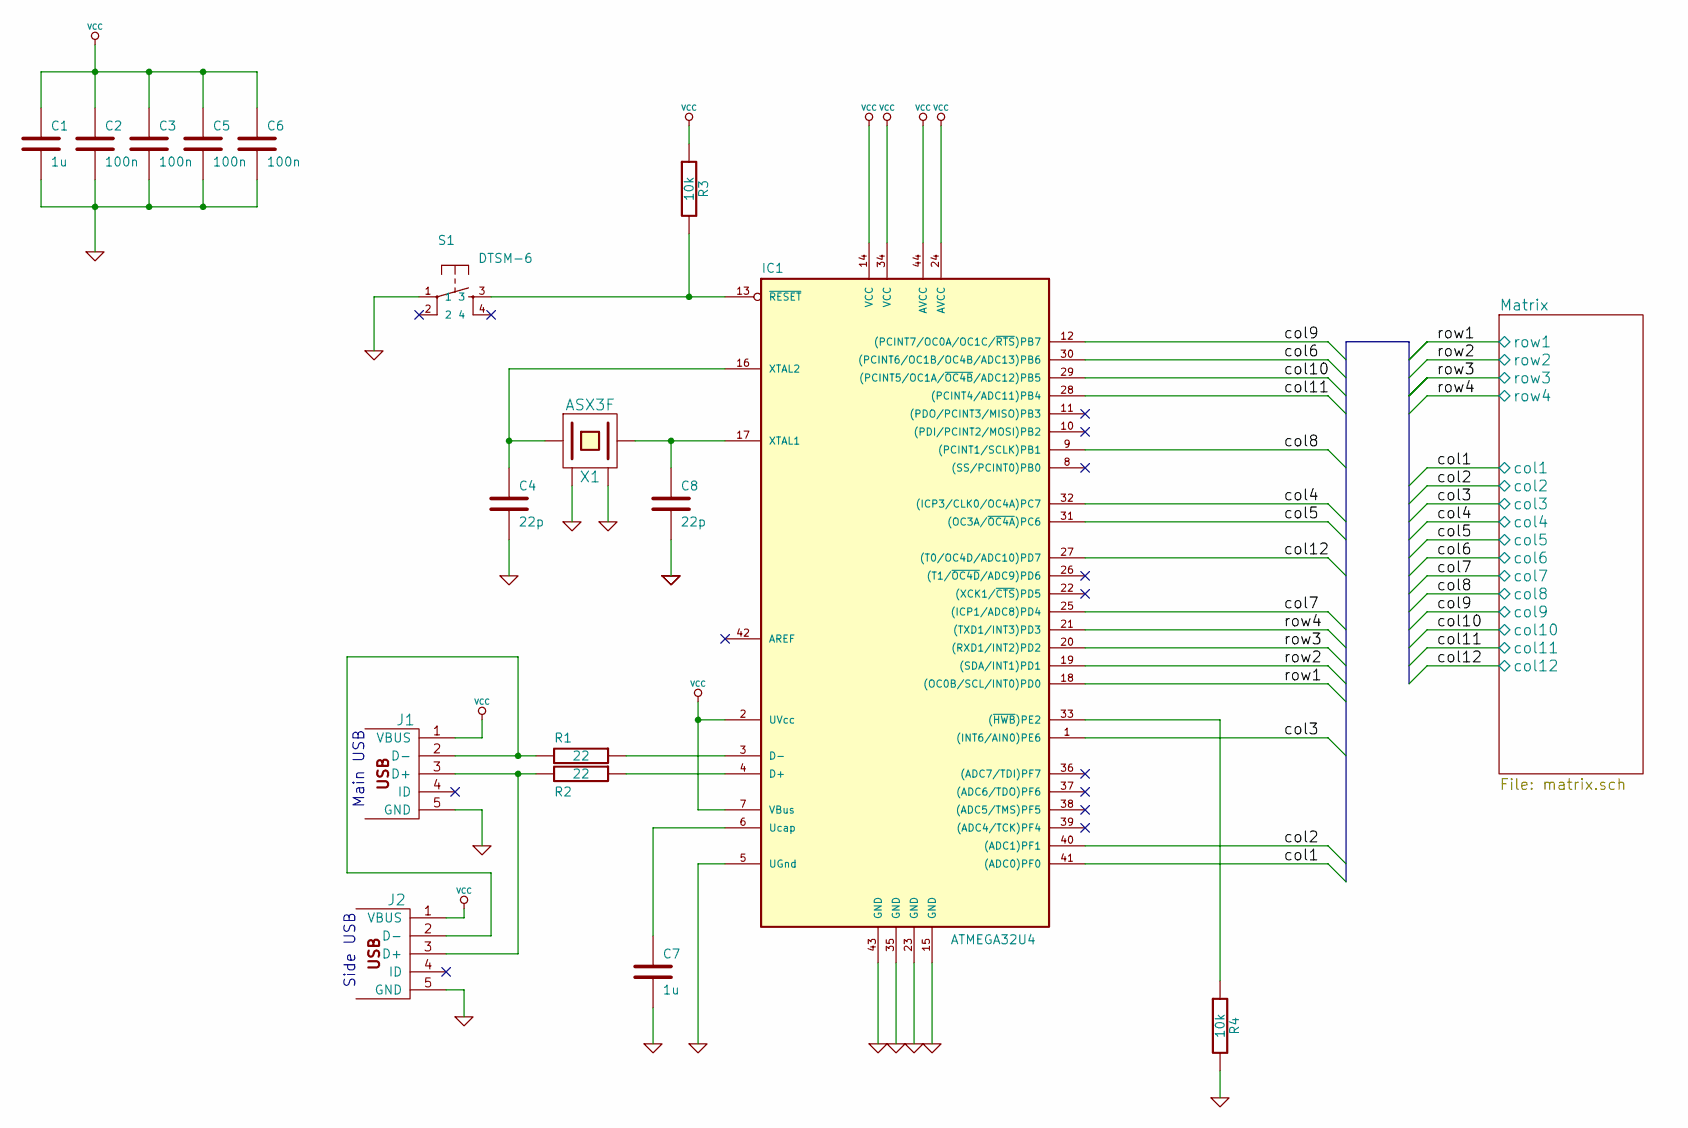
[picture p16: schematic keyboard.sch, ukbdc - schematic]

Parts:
C1, C7: 1u
C2, C3, C5, C6: 100n
C4, C8: 22p
IC1: ATMEGA32U4; TQFP44
J1: MINI
J2: USBMINI_B05
R1, R2: 22
R3, R4: 10k
S1: DTSM-6; switch-tact-DTSM-6
X1: ASX3F

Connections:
/Matrix/col1: IC1.41 ((ADC0)PF0); also elsewhere on the board
/Matrix/col2: IC1.40 ((ADC1)PF1); also elsewhere on the board
/Matrix/col3: IC1.1 ((INT6/AIN0)PE6); also elsewhere on the board
/Matrix/col4: IC1.32 ((ICP3/CLK0/OC4A)PC7); also elsewhere on the board
/Matrix/col5: IC1.31 ((OC3A/~OC4A~)PC6); also elsewhere on the board
/Matrix/col6: IC1.30 ((PCINT6/OC1B/OC4B/ADC13)PB6); also elsewhere on the board
/Matrix/col7: IC1.25 ((ICP1/ADC8)PD4); also elsewhere on the board
/Matrix/col8: IC1.9 ((PCINT1/SCLK)PB1); also elsewhere on the board
/Matrix/col9: IC1.12 ((PCINT7/OC0A/OC1C/~RTS~)PB7); also elsewhere on the board
/Matrix/col10: IC1.29 ((PCINT5/OC1A/~OC4B~/ADC12)PB5); also elsewhere on the board
/Matrix/col11: IC1.28 ((PCINT4/ADC11)PB4); also elsewhere on the board
/Matrix/col12: IC1.27 ((T0/OC4D/ADC10)PD7); also elsewhere on the board
/Matrix/row1: IC1.18 ((OC0B/SCL/INT0)PD0); also elsewhere on the board
/Matrix/row2: IC1.19 ((SDA/INT1)PD1); also elsewhere on the board
/Matrix/row3: IC1.20 ((RXD1/INT2)PD2); also elsewhere on the board
/Matrix/row4: IC1.21 ((TXD1/INT3)PD3); also elsewhere on the board
GND: C1.2, C2.2, C3.2, C4.2, C5.2, C6.2, C7.2, C8.2, IC1.5 (UGnd), IC1.15 (GND), IC1.23 (GND), IC1.35 (GND), IC1.43 (GND), J1.5 (GND), J2.5 (GND), R4.2, S1.1, X1.2 (GND), X1.4 (GND)
unnamed: IC1.33 ((~HWB~)PE2), R4.1
unnamed: C8.1, IC1.17 (XTAL1), X1.3 (2)
unnamed: J1.3 (D+), J2.3 (D+), R2.2
unnamed: J1.2 (D-), J2.2 (D-), R1.2
unnamed: C7.1, IC1.6 (Ucap)
unnamed: IC1.4 (D+), R2.1
unnamed: IC1.3 (D-), R1.1
unnamed: C4.1, IC1.16 (XTAL2), X1.1
unnamed: IC1.13 (~RESET~), R3.2, S1.3
VCC: C1.1, C2.1, C3.1, C5.1, C6.1, IC1.2 (UVcc), IC1.7 (VBus), IC1.14 (VCC), IC1.24 (AVCC), IC1.34 (VCC), IC1.44 (AVCC), J1.1 (VBUS), J2.1 (VBUS), R3.1

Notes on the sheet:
Side USB
Main USB

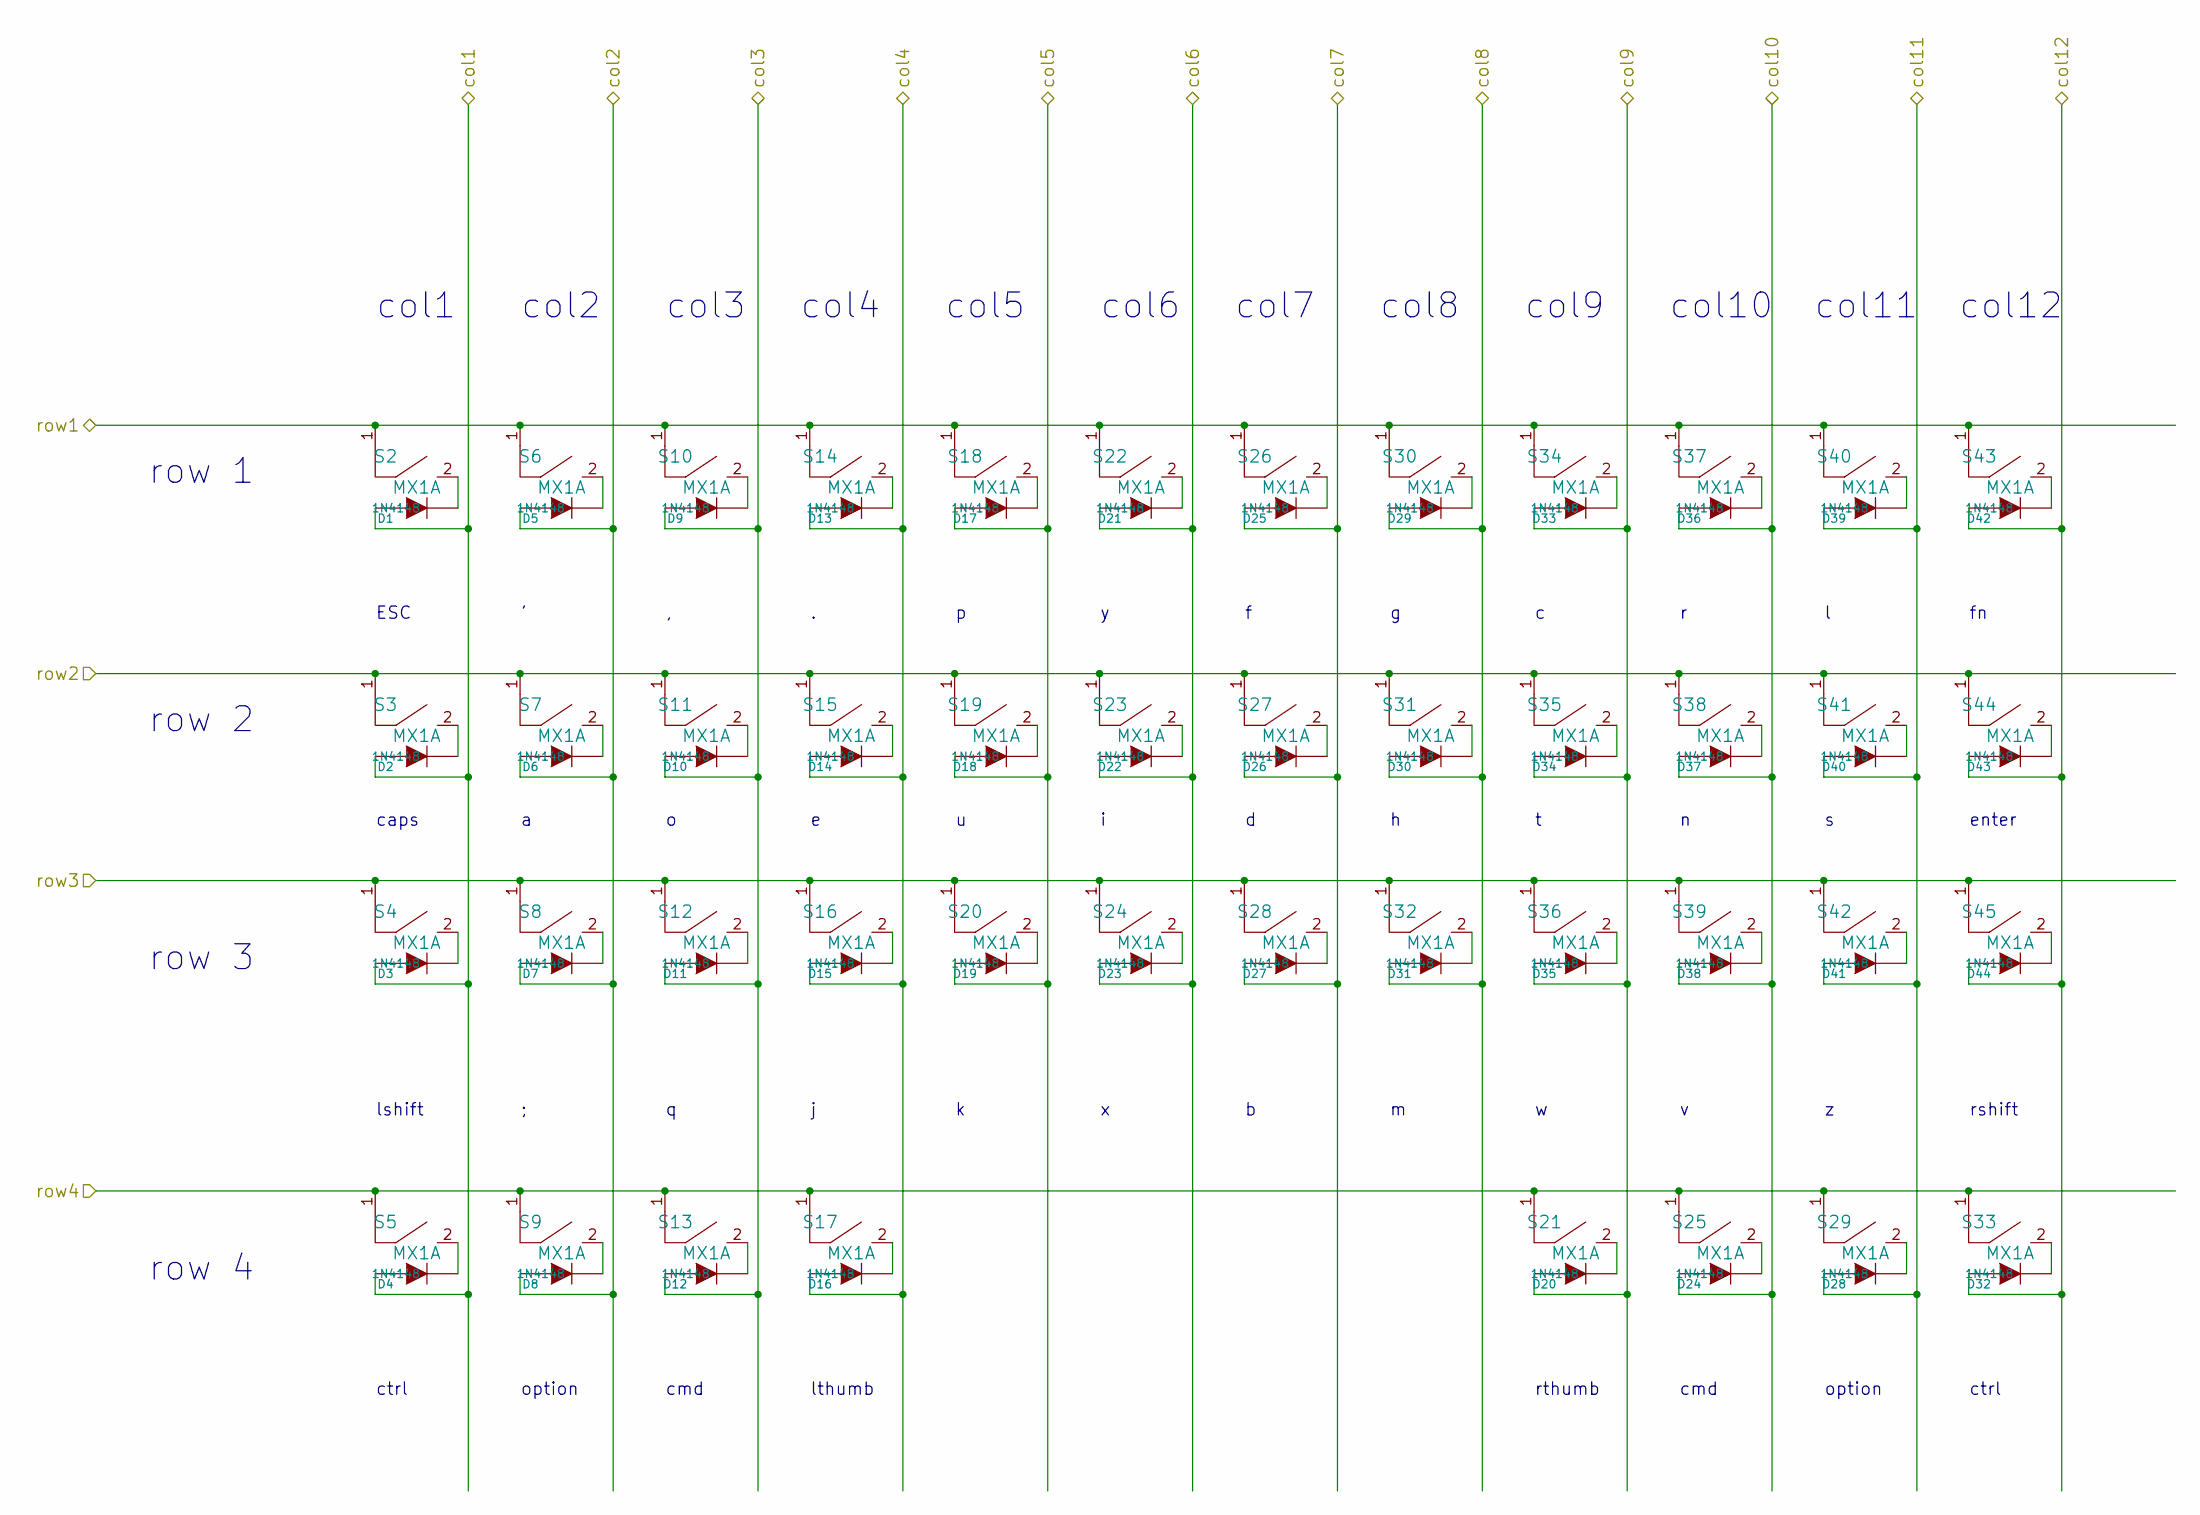
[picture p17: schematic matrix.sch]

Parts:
D1, D2, D3, D4, D5, D6, D7, D8, D9, D10, D11, D12, D13, D14, D15, D16, D17, D18, D19, D20, D21, D22, D23, D24, D25, D26, D27, D28, D29, D30, D31, D32, D33, D34, D35, D36, D37, D38, D39, D40, D41, D42, D43, D44: 1N4148
S2, S3, S4, S5, S6, S7, S8, S9, S10, S11, S12, S13, S14, S15, S16, S17, S18, S19, S20, S21, S22, S23, S24, S25, S26, S27, S28, S29, S30, S31, S32, S33, S34, S35, S36, S37, S38, S39, S40, S41, S42, S43, S44, S45: MX1A

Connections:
/Matrix/col1: D1.1 (A), D2.1 (A), D3.1 (A), D4.1 (A); also elsewhere on the board
/Matrix/col2: D5.1 (A), D6.1 (A), D7.1 (A), D8.1 (A); also elsewhere on the board
/Matrix/col3: D9.1 (A), D10.1 (A), D11.1 (A), D12.1 (A); also elsewhere on the board
/Matrix/col4: D13.1 (A), D14.1 (A), D15.1 (A), D16.1 (A); also elsewhere on the board
/Matrix/col5: D17.1 (A), D18.1 (A), D19.1 (A); also elsewhere on the board
/Matrix/col6: D21.1 (A), D22.1 (A), D23.1 (A); also elsewhere on the board
/Matrix/col7: D25.1 (A), D26.1 (A), D27.1 (A); also elsewhere on the board
/Matrix/col8: D29.1 (A), D30.1 (A), D31.1 (A); also elsewhere on the board
/Matrix/col9: D20.1 (A), D33.1 (A), D34.1 (A), D35.1 (A); also elsewhere on the board
/Matrix/col10: D24.1 (A), D36.1 (A), D37.1 (A), D38.1 (A); also elsewhere on the board
/Matrix/col11: D28.1 (A), D39.1 (A), D40.1 (A), D41.1 (A); also elsewhere on the board
/Matrix/col12: D32.1 (A), D42.1 (A), D43.1 (A), D44.1 (A); also elsewhere on the board
/Matrix/row1: S2.1, S6.1, S10.1, S14.1, S18.1, S22.1, S26.1, S30.1, S34.1, S37.1, S40.1, S43.1; also elsewhere on the board
/Matrix/row2: S3.1, S7.1, S11.1, S15.1, S19.1, S23.1, S27.1, S31.1, S35.1, S38.1, S41.1, S44.1; also elsewhere on the board
/Matrix/row3: S4.1, S8.1, S12.1, S16.1, S20.1, S24.1, S28.1, S32.1, S36.1, S39.1, S42.1, S45.1; also elsewhere on the board
/Matrix/row4: S5.1, S9.1, S13.1, S17.1, S21.1, S25.1, S29.1, S33.1; also elsewhere on the board
unnamed: D25.2 (K), S26.2
unnamed: D17.2 (K), S18.2
unnamed: D1.2 (K), S2.2
unnamed: D19.2 (K), S20.2
unnamed: D34.2 (K), S35.2
unnamed: D35.2 (K), S36.2
unnamed: D18.2 (K), S19.2
unnamed: D31.2 (K), S32.2
unnamed: D27.2 (K), S28.2
unnamed: D30.2 (K), S31.2
unnamed: D33.2 (K), S34.2
unnamed: D29.2 (K), S30.2
unnamed: D26.2 (K), S27.2
unnamed: D12.2 (K), S13.2
unnamed: D8.2 (K), S9.2
unnamed: D11.2 (K), S12.2
unnamed: D10.2 (K), S11.2
unnamed: D7.2 (K), S8.2
unnamed: D6.2 (K), S7.2
unnamed: D2.2 (K), S3.2
unnamed: D9.2 (K), S10.2
unnamed: D5.2 (K), S6.2
unnamed: D13.2 (K), S14.2
unnamed: D16.2 (K), S17.2
unnamed: D15.2 (K), S16.2
unnamed: D14.2 (K), S15.2
unnamed: D24.2 (K), S25.2
unnamed: D23.2 (K), S24.2
unnamed: D22.2 (K), S23.2
unnamed: D21.2 (K), S22.2
unnamed: D4.2 (K), S5.2
unnamed: D3.2 (K), S4.2
unnamed: D20.2 (K), S21.2
unnamed: D42.2 (K), S43.2
unnamed: D43.2 (K), S44.2
unnamed: D41.2 (K), S42.2
unnamed: D44.2 (K), S45.2
unnamed: D38.2 (K), S39.2
unnamed: D40.2 (K), S41.2
unnamed: D39.2 (K), S40.2
unnamed: D37.2 (K), S38.2
unnamed: D36.2 (K), S37.2
unnamed: D32.2 (K), S33.2
unnamed: D28.2 (K), S29.2

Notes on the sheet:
row 1
row 2
row 3
row 4
col1
col2
col3
col4
col5
col6
col7
col9
col10
col11
col12
col8
ESC
caps
enter
rshift
ctrl
option
cmd
lthumb
rthumb
lshift

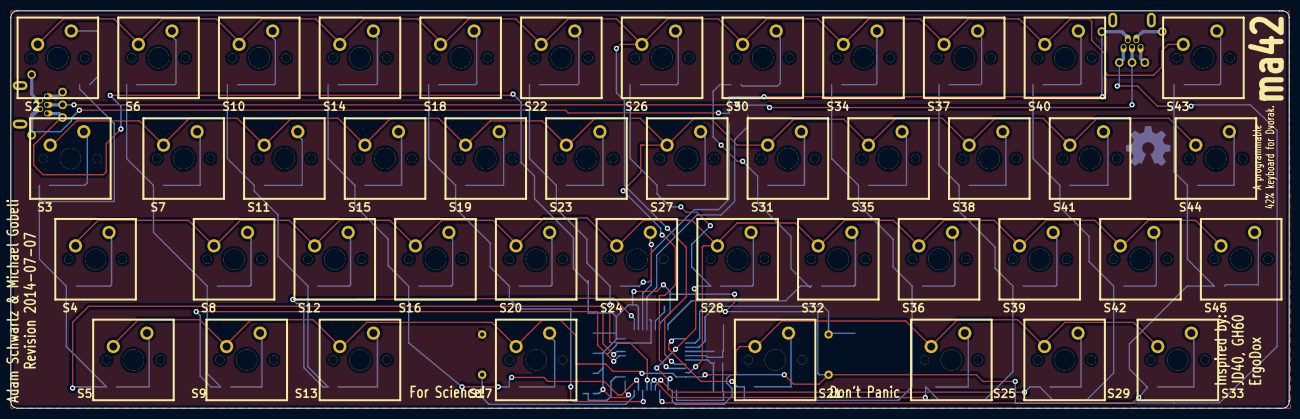
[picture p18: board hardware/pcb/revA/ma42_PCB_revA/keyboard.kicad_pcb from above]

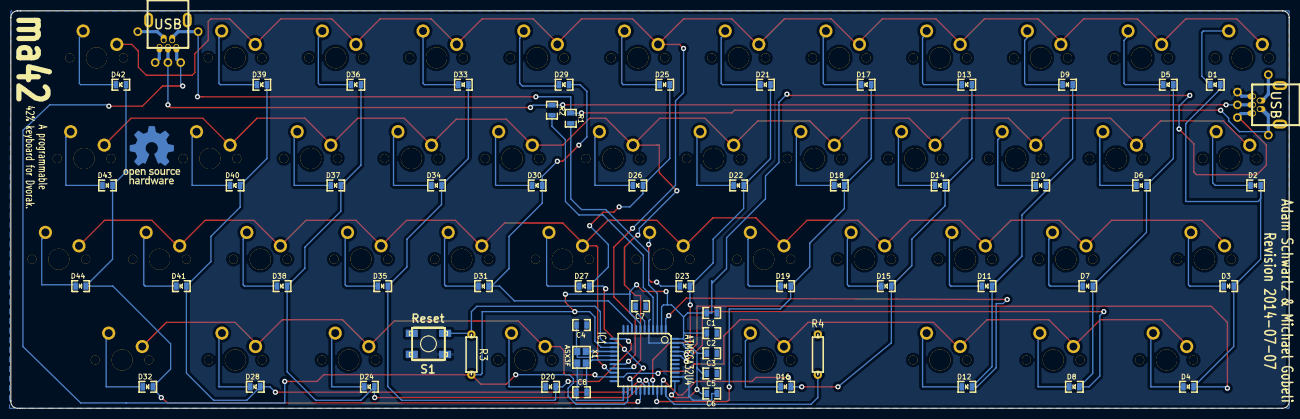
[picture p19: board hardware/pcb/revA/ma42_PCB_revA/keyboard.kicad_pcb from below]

Board: 2 copper layers, 241.8 x 75.2 mm, 105 parts (61 on the bottom side), 71 nets.

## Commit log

2014-07-13 add pcb
2014-07-21 added revA and started work on revB PCB
    [bom.xls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]
2014-07-21 add Case / Plate
    [MA42 - Copy.dwg, MA42.dwg]
2014-07-29 working on revB
    [MA42 - Copy.dwg, MA42.dwg, keyboard.kicad_pcb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]
2014-07-29 add revB PCB and Case
    [Assembly1.0002.iam, Assembly1.iam, Base.0002.ipt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]
2014-08-29 various project file updates
    [Assembly1.0002.iam, Assembly1.0003.iam, Assembly1.iam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]
2014-10-18 cleanup revB files
    [Assembly1.0002.iam]
2015-01-01 separate into 'hardware' and 'software' directories
    [Assembly1.0002.iam, Assembly1.0003.iam, Assembly1.iam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]
2015-05-19 cleanup hardware/ and provide working firmware hex
    add sample ma42_firmware.hex
    update software/setup.markdown
    add software/resources.markdown
    remove remaining .DS_Store files
    remove cache of software/inpiration/tmk_keyboard
    reorganize revA pcb archives
    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
    [bom.xls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]
2015-05-19 update project readme
    add pcb readme
2017-06-10 update bom
    [Switch Position.xlsx, bom UPDATED.xls, keyboard.kicad_pcb]
2021-11-30 add photo of pcb to readme
